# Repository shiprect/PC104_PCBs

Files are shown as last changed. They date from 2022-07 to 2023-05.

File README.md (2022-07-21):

# PC104_PCBs
This repository contains a collection of PC104 form factor PCB designs used on a variety of projects.

__Branches__

_previous-revision_  :  for the previous iteration of the pcb that was manufactured

_current-revision_   :  the pcb files that we are currently updating/working on

_production_         : for the version we have currently ordered/produced/are testing

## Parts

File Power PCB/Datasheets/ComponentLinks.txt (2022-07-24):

Solar Cells
https://www.digikey.com/en/products/detail/anysolar-ltd/KXOB25-14X1F-TR/9990479

Bat54 Schottky Diode
https://www.digikey.com/en/products/detail/onsemi/BAT54LT1G/917810

Power Good Switch
https://www.mouser.com/ProductDetail/Texas-Instruments/TPS22810DBVR?qs=34RfhUjJmKcFqeJVMZZhPA%3D%3D

Batteries
https://www.digikey.com/en/products/detail/zeus-battery-products/PCIFR18650-1500/9828824

Battery Charger
https://www.digikey.com/en/products/detail/analog-devices-inc/LTC4162IUFD-FAD-PBF/9446112

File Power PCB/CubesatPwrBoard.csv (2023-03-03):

Source: | /home/khronos/Desktop/Power PCB/CubesatPwrBoard.kicad_sch
Date: | Wed 09 Nov 2022 06:24:06 PM CST
Tool: | Eeschema 6.0.7
Generator: | /usr/share/kicad/plugins/bom_csv_grouped_by_value.py
Component Count: | 119
Individual Components:
Item | Qty | Reference(s) | Value | LibPart | Footprint | Datasheet | MANUFACTURER | MAXIMUM_PACKAGE_HEIGHT | PARTREV | STANDARD
 |  | BT1 | 254TR | 254TR:254TR | 254TR:BAT_254TR |  | Keystone Electronics | 17.215 mm | A | Manufacturer Recommendations
 |  | BT2 | 254TR | 254TR:254TR | 254TR:BAT_254TR |  | Keystone Electronics | 17.215 mm | A | Manufacturer Recommendations
 |  | BT3 | 254TR | 254TR:254TR | 254TR:BAT_254TR |  | Keystone Electronics | 17.215 mm | A | Manufacturer Recommendations
 |  | BT4 | 254TR | 254TR:254TR | 254TR:BAT_254TR |  | Keystone Electronics | 17.215 mm | A | Manufacturer Recommendations
 |  | BT5 | 254TR | 254TR:254TR | 254TR:BAT_254TR |  | Keystone Electronics | 17.215 mm | A | Manufacturer Recommendations
 |  | BT6 | 254TR | 254TR:254TR | 254TR:BAT_254TR |  | Keystone Electronics | 17.215 mm | A | Manufacturer Recommendations
 |  | BT7 | 254TR | 254TR:254TR | 254TR:BAT_254TR |  | Keystone Electronics | 17.215 mm | A | Manufacturer Recommendations
 |  | BT8 | 254TR | 254TR:254TR | 254TR:BAT_254TR |  | Keystone Electronics | 17.215 mm | A | Manufacturer Recommendations
 |  | C1 | C_Polarized_US | Device:C_Polarized_US | Capacitor_SMD:C_0603_1608Metric_Pad1.08x0.95mm_HandSolder | ~
 |  | C2 | C_Polarized_US | Device:C_Polarized_US | Capacitor_SMD:C_0603_1608Metric_Pad1.08x0.95mm_HandSolder | ~
 |  | C3 | C | Device:C | Capacitor_SMD:C_0603_1608Metric_Pad1.08x0.95mm_HandSolder | ~
 |  | C4 | C | Device:C | Capacitor_SMD:C_0603_1608Metric_Pad1.08x0.95mm_HandSolder | ~
 |  | C5 | C | Device:C | Capacitor_SMD:C_0603_1608Metric_Pad1.08x0.95mm_HandSolder | ~
 |  | C6 | C | Device:C | Capacitor_SMD:C_0603_1608Metric_Pad1.08x0.95mm_HandSolder | ~
 |  | C7 | C | Device:C | Capacitor_SMD:C_0603_1608Metric_Pad1.08x0.95mm_HandSolder | ~
 |  | C8 | 150u | Device:C_Polarized_US | Capacitor_SMD:C_0603_1608Metric_Pad1.08x0.95mm_HandSolder | ~
 |  | C9 | C_Polarized_US | Device:C_Polarized_US | Capacitor_SMD:C_0603_1608Metric_Pad1.08x0.95mm_HandSolder | ~
 |  | C10 | 1u | Device:C | Capacitor_SMD:C_0603_1608Metric_Pad1.08x0.95mm_HandSolder | ~
 |  | C11 | 4.7u | Device:C | Capacitor_SMD:C_0603_1608Metric_Pad1.08x0.95mm_HandSolder | ~
 |  | C12 | C | Device:C | Capacitor_SMD:C_0603_1608Metric_Pad1.08x0.95mm_HandSolder | ~
 |  | C13 | 10u | Device:C | Capacitor_SMD:C_0603_1608Metric_Pad1.08x0.95mm_HandSolder | ~
 |  | C14 | 10u | Device:C | Capacitor_SMD:C_0603_1608Metric_Pad1.08x0.95mm_HandSolder | ~
 |  | C15 | 150u | Device:C_Polarized_US | Capacitor_SMD:C_0603_1608Metric_Pad1.08x0.95mm_HandSolder | ~
 |  | C16 | C_Polarized_US | Device:C_Polarized_US | Capacitor_SMD:C_0603_1608Metric_Pad1.08x0.95mm_HandSolder | ~
 |  | C17 | 1u | Device:C | Capacitor_SMD:C_0603_1608Metric_Pad1.08x0.95mm_HandSolder | ~
 |  | C18 | 4.7u | Device:C | Capacitor_SMD:C_0603_1608Metric_Pad1.08x0.95mm_HandSolder | ~
 |  | C19 | C | Device:C | Capacitor_SMD:C_0603_1608Metric_Pad1.08x0.95mm_HandSolder | ~
 |  | C20 | 10u | Device:C | Capacitor_SMD:C_0603_1608Metric_Pad1.08x0.95mm_HandSolder | ~
 |  | C21 | 10u | Device:C | Capacitor_SMD:C_0603_1608Metric_Pad1.08x0.95mm_HandSolder | ~
 |  | C22 | 150u | Device:C_Polarized_US | Capacitor_SMD:C_0603_1608Metric_Pad1.08x0.95mm_HandSolder | ~
 |  | C23 | C_Polarized_US | Device:C_Polarized_US | Capacitor_SMD:C_0603_1608Metric_Pad1.08x0.95mm_HandSolder | ~
 |  | C24 | 1u | Device:C | Capacitor_SMD:C_0603_1608Metric_Pad1.08x0.95mm_HandSolder | ~
 |  | C25 | 4.7u | Device:C | Capacitor_SMD:C_0603_1608Metric_Pad1.08x0.95mm_HandSolder | ~
 |  | C26 | C | Device:C | Capacitor_SMD:C_0603_1608Metric_Pad1.08x0.95mm_HandSolder | ~
 |  | C27 | 10u | Device:C | Capacitor_SMD:C_0603_1608Metric_Pad1.08x0.95mm_HandSolder | ~
 |  | C28 | 10u | Device:C | Capacitor_SMD:C_0603_1608Metric_Pad1.08x0.95mm_HandSolder | ~
 |  | C29 | C_Polarized_US | Device:C_Polarized_US | Capacitor_SMD:C_0603_1608Metric_Pad1.08x0.95mm_HandSolder | ~
 |  | C30 | C_Polarized_US | Device:C_Polarized_US | Capacitor_SMD:C_0603_1608Metric_Pad1.08x0.95mm_HandSolder | ~
 |  | C31 | 4.7u | Device:C_Polarized_US | Capacitor_SMD:C_0603_1608Metric_Pad1.08x0.95mm_HandSolder | ~
 |  | C32 | 100u | Device:C_Polarized_US | Capacitor_SMD:C_0603_1608Metric_Pad1.08x0.95mm_HandSolder | ~
 |  | C33 | 4.7u | Device:C_Polarized_US | Capacitor_SMD:C_0603_1608Metric_Pad1.08x0.95mm_HandSolder | ~
 |  | C34 | 100u | Device:C_Polarized_US | Capacitor_SMD:C_0603_1608Metric_Pad1.08x0.95mm_HandSolder | ~
 |  | C35 | 4.7u | Device:C_Polarized_US | Capacitor_SMD:C_0603_1608Metric_Pad1.08x0.95mm_HandSolder | ~
 |  | C36 | 100u | Device:C_Polarized_US | Capacitor_SMD:C_0603_1608Metric_Pad1.08x0.95mm_HandSolder | ~
 |  | D1 | D_Schottky_Small | Device:D_Schottky_Small | CUS520,H3F:DIO_CUS520,H3F | ~
 |  | D2 | D_Schottky_Small | Device:D_Schottky_Small | CUS520,H3F:DIO_CUS520,H3F | ~
 |  | D3 | D_Schottky_Small | Device:D_Schottky_Small | CUS520,H3F:DIO_CUS520,H3F | ~
 |  | D4 | D_Schottky_Small | Device:D_Schottky_Small | CUS520,H3F:DIO_CUS520,H3F | ~
 |  | D5 | D_Schottky | Device:D_Schottky | Diode_SMD:D_0603_1608Metric_Pad1.05x0.95mm_HandSolder | ~
 |  | D6 | D_Schottky | Device:D_Schottky | Diode_SMD:D_0603_1608Metric_Pad1.05x0.95mm_HandSolder | ~
 |  | D7 | D_Schottky | Device:D_Schottky | Diode_SMD:D_0603_1608Metric_Pad1.05x0.95mm_HandSolder | ~
 |  | D8 | D_Schottky | Device:D_Schottky | Diode_SMD:D_0603_1608Metric_Pad1.05x0.95mm_HandSolder | ~
 |  | H1 | MountingHole_Pad | Mechanical:MountingHole_Pad | MountingHole:MountingHole_4.3mm_M4_DIN965_Pad | ~
 |  | H2 | MountingHole_Pad | Mechanical:MountingHole_Pad | MountingHole:MountingHole_4.3mm_M4_DIN965_Pad | ~
 |  | H3 | MountingHole_Pad | Mechanical:MountingHole_Pad | MountingHole:MountingHole_4.3mm_M4_DIN965_Pad | ~
 |  | H4 | MountingHole_Pad | Mechanical:MountingHole_Pad | MountingHole:MountingHole_4.3mm_M4_DIN965_Pad | ~
 |  | J1 | Conn_01x04_Female | Connector:Conn_01x04_Female | Connector_PinHeader_2.54mm:PinHeader_1x04_P2.54mm_Vertical | ~
 |  | J2 | Conn_01x04_Female | Connector:Conn_01x04_Female | Connector_PinHeader_2.54mm:PinHeader_1x04_P2.54mm_Vertical | ~
 |  | J3 | Conn_01x04_Female | Connector:Conn_01x04_Female | Connector_PinHeader_2.54mm:PinHeader_1x04_P2.54mm_Vertical | ~
 |  | J4 | Conn_01x04_Female | Connector:Conn_01x04_Female | Connector_PinHeader_2.54mm:PinHeader_1x04_P2.54mm_Vertical | ~
 |  | J5 | Conn_01x04_Female | Connector:Conn_01x04_Female | Connector_PinHeader_2.54mm:PinHeader_1x04_P2.54mm_Vertical | ~
 |  | J6 | Conn_01x03_Female | Connector:Conn_01x03_Female | Connector_PinSocket_2.54mm:PinSocket_1x03_P2.54mm_Vertical | ~
 |  | J7 | Conn_01x03_Female | Connector:Conn_01x03_Female | Connector_PinSocket_2.54mm:PinSocket_1x03_P2.54mm_Vertical | ~
 |  | J8 | Conn_01x03_Female | Connector:Conn_01x03_Female | Connector_PinSocket_2.54mm:PinSocket_1x03_P2.54mm_Vertical | ~
 |  | J9 | Conn_01x03_Female | Connector:Conn_01x03_Female | Connector_PinSocket_2.54mm:PinSocket_1x03_P2.54mm_Vertical | ~
 |  | J10 | S1 | Connector:Conn_01x08_Female | Connector_PinSocket_2.54mm:PinSocket_2x04_P2.54mm_Vertical | ~
 |  | J11 | S2 | Connector:Conn_01x08_Female | Connector_PinSocket_2.54mm:PinSocket_2x04_P2.54mm_Vertical | ~
 |  | J12 | S3 | Connector:Conn_01x08_Female | Connector_PinSocket_2.54mm:PinSocket_2x04_P2.54mm_Vertical | ~
 |  | J13 | S4 | Connector:Conn_01x08_Female | Connector_PinSocket_2.54mm:PinSocket_2x04_P2.54mm_Vertical | ~
 |  | J14 | S5 | Connector:Conn_01x08_Female | Connector_PinSocket_2.54mm:PinSocket_2x04_P2.54mm_Vertical | ~
 |  | J15 | S6 | Connector:Conn_01x08_Female | Connector_PinSocket_2.54mm:PinSocket_2x04_P2.54mm_Vertical | ~
 |  | L1 | L | Device:L | Inductor_SMD:L_0603_1608Metric_Pad1.05x0.95mm_HandSolder | ~
 |  | L2 | 4.7u | Device:L | Inductor_SMD:L_0603_1608Metric_Pad1.05x0.95mm_HandSolder | ~
 |  | L3 | 4.7u | Device:L | Inductor_SMD:L_0603_1608Metric_Pad1.05x0.95mm_HandSolder | ~
 |  | L4 | 4.7u | Device:L | Inductor_SMD:L_0603_1608Metric_Pad1.05x0.95mm_HandSolder | ~
 |  | L5 | L | Device:L | Inductor_SMD:L_0603_1608Metric_Pad1.05x0.95mm_HandSolder | ~
 |  | L6 | 22u | Device:L | Inductor_SMD:L_0603_1608Metric_Pad1.05x0.95mm_HandSolder | ~
 |  | L7 | 22u | Device:L | Inductor_SMD:L_0603_1608Metric_Pad1.05x0.95mm_HandSolder | ~
 |  | L8 | 22u | Device:L | Inductor_SMD:L_0603_1608Metric_Pad1.05x0.95mm_HandSolder | ~
 |  | Q1 | TQM110NB04CR_RLG | TQM110NB04CR_RLG:TQM110NB04CR_RLG | TQM110N:TRANS_TQM110NB04CR_RLG |  | Taiwan Semiconductor | 1.1 mm | A1910 | Manufacturer Recommendations
 |  | Q2 | 2N7002* | 2N7002_:2N7002* | 2N7002:SOT23
 |  | Q3 | TQM110NB04CR_RLG | TQM110NB04CR_RLG:TQM110NB04CR_RLG | TQM110N:TRANS_TQM110NB04CR_RLG |  | Taiwan Semiconductor | 1.1 mm | A1910 | Manufacturer Recommendations
 |  | Q4 | 2N7002* | 2N7002_:2N7002* | 2N7002:SOT23
 |  | Q5 | TQM110NB04CR_RLG | TQM110NB04CR_RLG:TQM110NB04CR_RLG | TQM110N:TRANS_TQM110NB04CR_RLG |  | Taiwan Semiconductor | 1.1 mm | A1910 | Manufacturer Recommendations
 |  | Q6 | 2N7002* | 2N7002_:2N7002* | 2N7002:SOT23
 |  | Q7 | TQM110NB04CR_RLG | TQM110NB04CR_RLG:TQM110NB04CR_RLG | TQM110N:TRANS_TQM110NB04CR_RLG |  | Taiwan Semiconductor | 1.1 mm | A1910 | Manufacturer Recommendations
 |  | Q8 | 2N7002* | 2N7002_:2N7002* | 2N7002:SOT23
 |  | R1 | R | Device:R | Resistor_SMD:R_0603_1608Metric_Pad0.98x0.95mm_HandSolder | ~
 |  | R2 | R | Device:R | Resistor_SMD:R_0603_1608Metric_Pad0.98x0.95mm_HandSolder | ~
 |  | R3 | R | Device:R | Resistor_SMD:R_0603_1608Metric_Pad0.98x0.95mm_HandSolder | ~
 |  | R4 | R | Device:R | Resistor_SMD:R_0603_1608Metric_Pad0.98x0.95mm_HandSolder | ~
 |  | R5 | R | Device:R | Resistor_SMD:R_0603_1608Metric_Pad0.98x0.95mm_HandSolder | ~
 |  | R6 | 2.5 | Device:R | Resistor_SMD:R_0603_1608Metric_Pad0.98x0.95mm_HandSolder | ~
 |  | R7 | 16m | Device:R | Resistor_SMD:R_0603_1608Metric_Pad0.98x0.95mm_HandSolder | ~
 |  | R8 | 16m | Device:R | Resistor_SMD:R_0603_1608Metric_Pad0.98x0.95mm_HandSolder | ~
 |  | R9 | 63.4k | Device:R | Resistor_SMD:R_0603_1608Metric_Pad0.98x0.95mm_HandSolder | ~
 |  | R10 | 10m | Device:R | Resistor_SMD:R_0603_1608Metric_Pad0.98x0.95mm_HandSolder | ~
 |  | R11 | 2.5 | Device:R | Resistor_SMD:R_0603_1608Metric_Pad0.98x0.95mm_HandSolder | ~
 |  | R12 | 16m | Device:R | Resistor_SMD:R_0603_1608Metric_Pad0.98x0.95mm_HandSolder | ~
 |  | R13 | 16m | Device:R | Resistor_SMD:R_0603_1608Metric_Pad0.98x0.95mm_HandSolder | ~
 |  | R14 | 63.4k | Device:R | Resistor_SMD:R_0603_1608Metric_Pad0.98x0.95mm_HandSolder | ~
 |  | R15 | 10m | Device:R | Resistor_SMD:R_0603_1608Metric_Pad0.98x0.95mm_HandSolder | ~
 |  | R16 | 2.5 | Device:R | Resistor_SMD:R_0603_1608Metric_Pad0.98x0.95mm_HandSolder | ~
 |  | R17 | 16m | Device:R | Resistor_SMD:R_0603_1608Metric_Pad0.98x0.95mm_HandSolder | ~
 |  | R18 | 16m | Device:R | Resistor_SMD:R_0603_1608Metric_Pad0.98x0.95mm_HandSolder | ~
 |  | R19 | 63.4k | Device:R | Resistor_SMD:R_0603_1608Metric_Pad0.98x0.95mm_HandSolder | ~
 |  | R20 | 10m | Device:R | Resistor_SMD:R_0603_1608Metric_Pad0.98x0.95mm_HandSolder | ~
 |  | TH1 | Thermistor_NTC | Device:Thermistor_NTC | Resistor_SMD:R_0402_1005Metric_Pad0.72x0.64mm_HandSolder | ~
 |  | TH2 | Thermistor_NTC | Device:Thermistor_NTC | Resistor_SMD:R_0402_1005Metric_Pad0.72x0.64mm_HandSolder | ~
 |  | TH3 | Thermistor_NTC | Device:Thermistor_NTC | Resistor_SMD:R_0402_1005Metric_Pad0.72x0.64mm_HandSolder | ~
 |  | TH4 | Thermistor_NTC | Device:Thermistor_NTC | Resistor_SMD:R_0402_1005Metric_Pad0.72x0.64mm_HandSolder | ~
 |  | U1 | LTC4162 | LTC4162IUFD:LTC4162 | LTC4162:QFN50P500X400X80-29N
 |  | U2 | LTC4162 | LTC4162IUFD:LTC4162 | LTC4162:QFN50P500X400X80-29N
 |  | U3 | LTC4162 | LTC4162IUFD:LTC4162 | LTC4162:QFN50P500X400X80-29N
 |  | U4 | LTC4162 | LTC4162IUFD:LTC4162 | LTC4162:QFN50P500X400X80-29N
 |  | U5 | MAX710ESE+T | MAX710ESE_T:MAX710ESE+T | MAX710ESE:SOIC127P600X175-16N
 |  | U6 | MAX710ESE+T | MAX710ESE_T:MAX710ESE+T | MAX710ESE:SOIC127P600X175-16N
 |  | U7 | MAX710ESE+T | MAX710ESE_T:MAX710ESE+T | MAX710ESE:SOIC127P600X175-16N
 |  | U8 | MAX710ESE+T | MAX710ESE_T:MAX710ESE+T | MAX710ESE:SOIC127P600X175-16N
Collated Components:
Item | Qty | Reference(s) | Value | LibPart | Footprint | Datasheet | MANUFACTURER | MAXIMUM_PACKAGE_HEIGHT | PARTREV | STANDARD
1 | 8 | BT1, BT2, BT3, BT4, BT5, BT6, BT7, BT8 | 254TR | 254TR:254TR | 254TR:BAT_254TR |  | Keystone Electronics | 17.215 mm | A | Manufacturer Recommendations
2 | 7 | C1, C2, C9, C16, C23, C29, C30 | C_Polarized_US | Device:C_Polarized_US | Capacitor_SMD:C_0603_1608Metric_Pad1.08x0.95mm_HandSolder | ~
3 | 8 | C3, C4, C5, C6, C7, C12, C19, C26 | C | Device:C | Capacitor_SMD:C_0603_1608Metric_Pad1.08x0.95mm_HandSolder | ~
4 | 3 | C8, C15, C22 | 150u | Device:C_Polarized_US | Capacitor_SMD:C_0603_1608Metric_Pad1.08x0.95mm_HandSolder | ~
5 | 3 | C10, C17, C24 | 1u | Device:C | Capacitor_SMD:C_0603_1608Metric_Pad1.08x0.95mm_HandSolder | ~
6 | 3 | C11, C18, C25 | 4.7u | Device:C | Capacitor_SMD:C_0603_1608Metric_Pad1.08x0.95mm_HandSolder | ~
7 | 6 | C13, C14, C20, C21, C27, C28 | 10u | Device:C | Capacitor_SMD:C_0603_1608Metric_Pad1.08x0.95mm_HandSolder | ~
8 | 3 | C31, C33, C35 | 4.7u | Device:C_Polarized_US | Capacitor_SMD:C_0603_1608Metric_Pad1.08x0.95mm_HandSolder | ~
9 | 3 | C32, C34, C36 | 100u | Device:C_Polarized_US | Capacitor_SMD:C_0603_1608Metric_Pad1.08x0.95mm_HandSolder | ~
10 | 4 | D1, D2, D3, D4 | D_Schottky_Small | Device:D_Schottky_Small | CUS520,H3F:DIO_CUS520,H3F | ~
11 | 4 | D5, D6, D7, D8 | D_Schottky | Device:D_Schottky | Diode_SMD:D_0603_1608Metric_Pad1.05x0.95mm_HandSolder | ~
12 | 4 | H1, H2, H3, H4 | MountingHole_Pad | Mechanical:MountingHole_Pad | MountingHole:MountingHole_4.3mm_M4_DIN965_Pad | ~
13 | 5 | J1, J2, J3, J4, J5 | Conn_01x04_Female | Connector:Conn_01x04_Female | Connector_PinHeader_2.54mm:PinHeader_1x04_P2.54mm_Vertical | ~
14 | 4 | J6, J7, J8, J9 | Conn_01x03_Female | Connector:Conn_01x03_Female | Connector_PinSocket_2.54mm:PinSocket_1x03_P2.54mm_Vertical | ~
15 | 1 | J10 | S1 | Connector:Conn_01x08_Female | Connector_PinSocket_2.54mm:PinSocket_2x04_P2.54mm_Vertical | ~
16 | 1 | J11 | S2 | Connector:Conn_01x08_Female | Connector_PinSocket_2.54mm:PinSocket_2x04_P2.54mm_Vertical | ~
17 | 1 | J12 | S3 | Connector:Conn_01x08_Female | Connector_PinSocket_2.54mm:PinSocket_2x04_P2.54mm_Vertical | ~
18 | 1 | J13 | S4 | Connector:Conn_01x08_Female | Connector_PinSocket_2.54mm:PinSocket_2x04_P2.54mm_Vertical | ~
19 | 1 | J14 | S5 | Connector:Conn_01x08_Female | Connector_PinSocket_2.54mm:PinSocket_2x04_P2.54mm_Vertical | ~
20 | 1 | J15 | S6 | Connector:Conn_01x08_Female | Connector_PinSocket_2.54mm:PinSocket_2x04_P2.54mm_Vertical | ~
21 | 2 | L1, L5 | L | Device:L | Inductor_SMD:L_0603_1608Metric_Pad1.05x0.95mm_HandSolder | ~
22 | 3 | L2, L3, L4 | 4.7u | Device:L | Inductor_SMD:L_0603_1608Metric_Pad1.05x0.95mm_HandSolder | ~
23 | 3 | L6, L7, L8 | 22u | Device:L | Inductor_SMD:L_0603_1608Metric_Pad1.05x0.95mm_HandSolder | ~
24 | 4 | Q1, Q3, Q5, Q7 | TQM110NB04CR_RLG | TQM110NB04CR_RLG:TQM110NB04CR_RLG | TQM110N:TRANS_TQM110NB04CR_RLG |  | Taiwan Semiconductor | 1.1 mm | A1910 | Manufacturer Recommendations
25 | 4 | Q2, Q4, Q6, Q8 | 2N7002* | 2N7002_:2N7002* | 2N7002:SOT23
26 | 5 | R1, R2, R3, R4, R5 | R | Device:R | Resistor_SMD:R_0603_1608Metric_Pad0.98x0.95mm_HandSolder | ~
27 | 3 | R6, R11, R16 | 2.5 | Device:R | Resistor_SMD:R_0603_1608Metric_Pad0.98x0.95mm_HandSolder | ~
28 | 6 | R7, R8, R12, R13, R17, R18 | 16m | Device:R | Resistor_SMD:R_0603_1608Metric_Pad0.98x0.95mm_HandSolder | ~
29 | 3 | R9, R14, R19 | 63.4k | Device:R | Resistor_SMD:R_0603_1608Metric_Pad0.98x0.95mm_HandSolder | ~
30 | 3 | R10, R15, R20 | 10m | Device:R | Resistor_SMD:R_0603_1608Metric_Pad0.98x0.95mm_HandSolder | ~
31 | 4 | TH1, TH2, TH3, TH4 | Thermistor_NTC | Device:Thermistor_NTC | Resistor_SMD:R_0402_1005Metric_Pad0.72x0.64mm_HandSolder | ~
32 | 4 | U1, U2, U3, U4 | LTC4162 | LTC4162IUFD:LTC4162 | LTC4162:QFN50P500X400X80-29N
33 | 4 | U5, U6, U7, U8 | MAX710ESE+T | MAX710ESE_T:MAX710ESE+T | MAX710ESE:SOIC127P600X175-16N

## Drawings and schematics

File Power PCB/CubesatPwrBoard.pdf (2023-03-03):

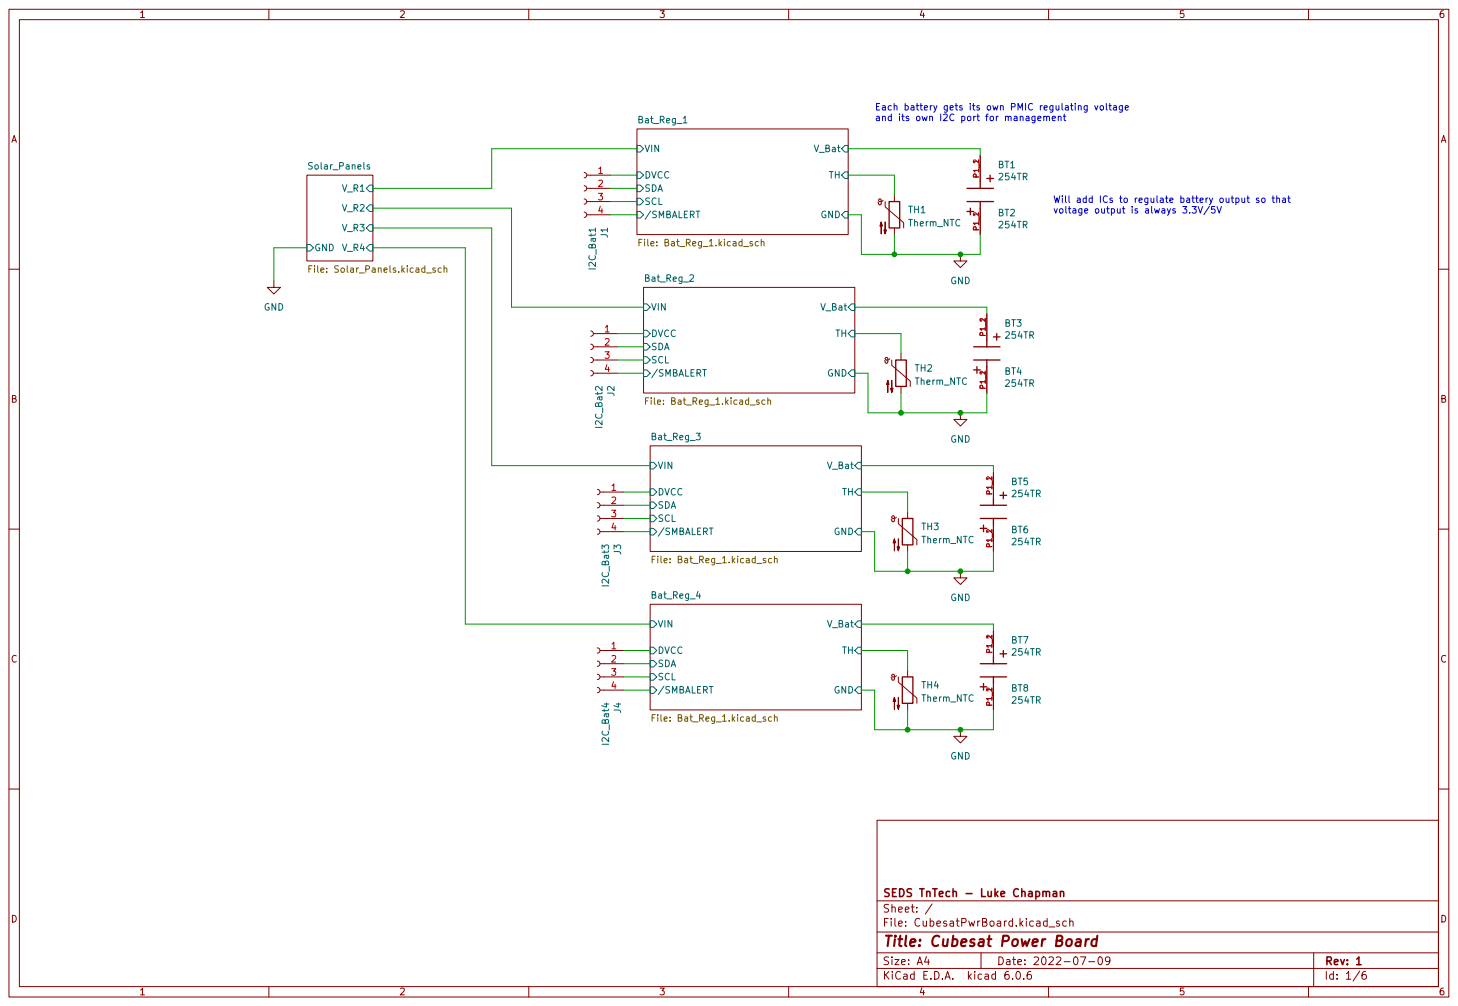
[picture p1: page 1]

Each battery gets its own PMIC regulating voltage
and its own I2C port for management

Will add ICs to regulate battery output so that
voltage output is always 3.3V/5V

File: CubesatPwrBoard.kicad_sch Sheet: / SEDS TnTech - Luke Chapman

Id: 1/6 Title: Cubesat Power Board

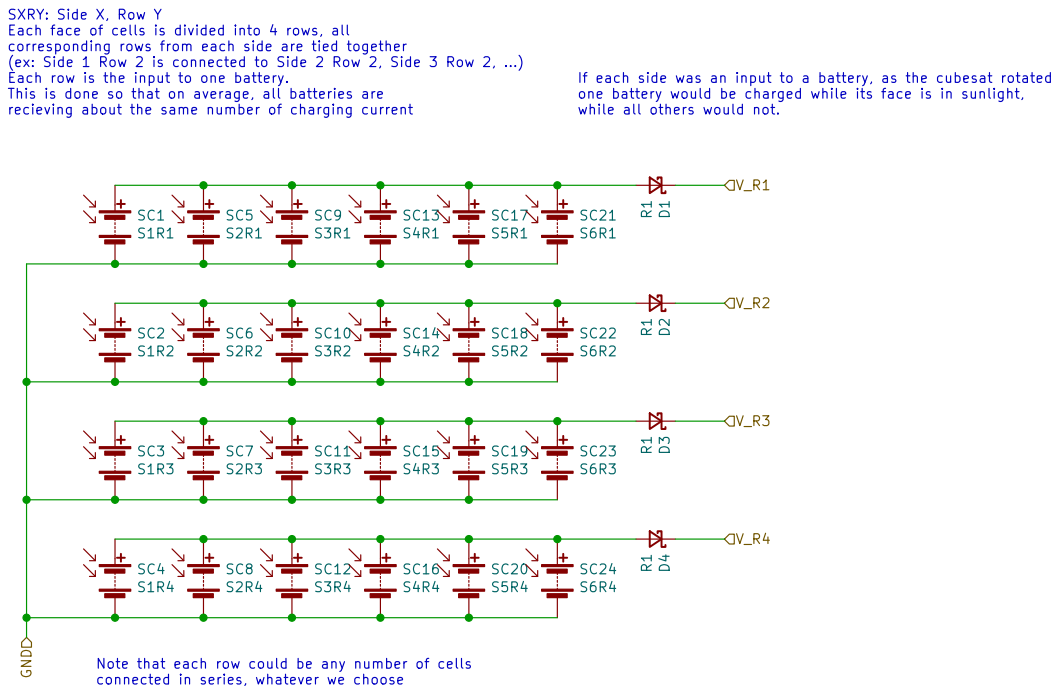
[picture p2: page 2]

V_R3 V_R4 V_R1 V_R2 SXRY: Side X, Row Y
Each face of cells is divided into 4 rows, all corresponding rows from each side are tied together

(ex: Side 1 Row 2 is connected to Side 2 Row 2, Side 3 Row 2, ...)
Each row is the input to one battery.
This is done so that on average, all batteries are
recieving about the same number of charging current

If each side was an input to a battery, as the cubesat rotated

one battery would be charged while its face is in sunlight, while all others would not. Note that each row could be any number of cells

connected in series, whatever we choose

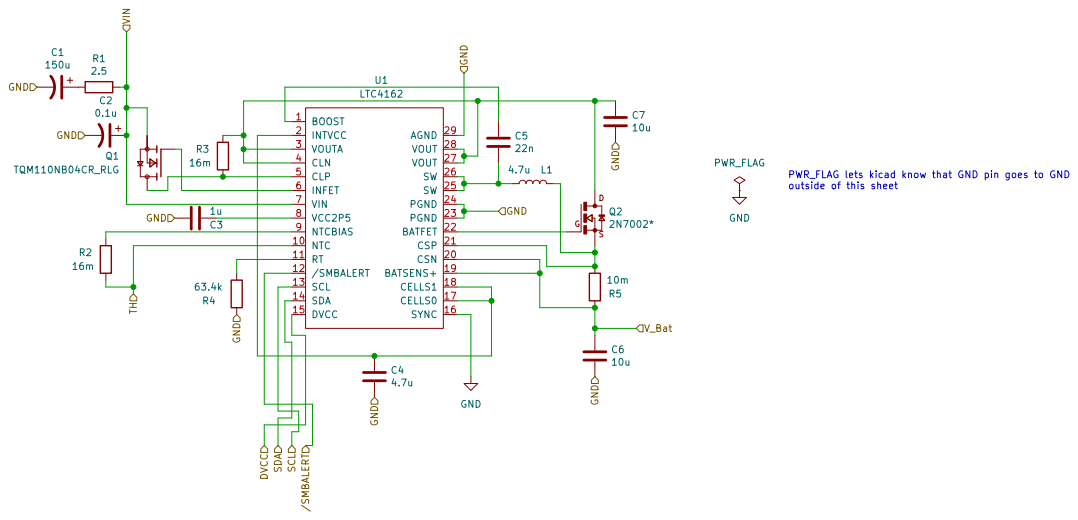
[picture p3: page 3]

PWR_FLAG lets kicad know that GND pin goes to GND
outside of this sheet

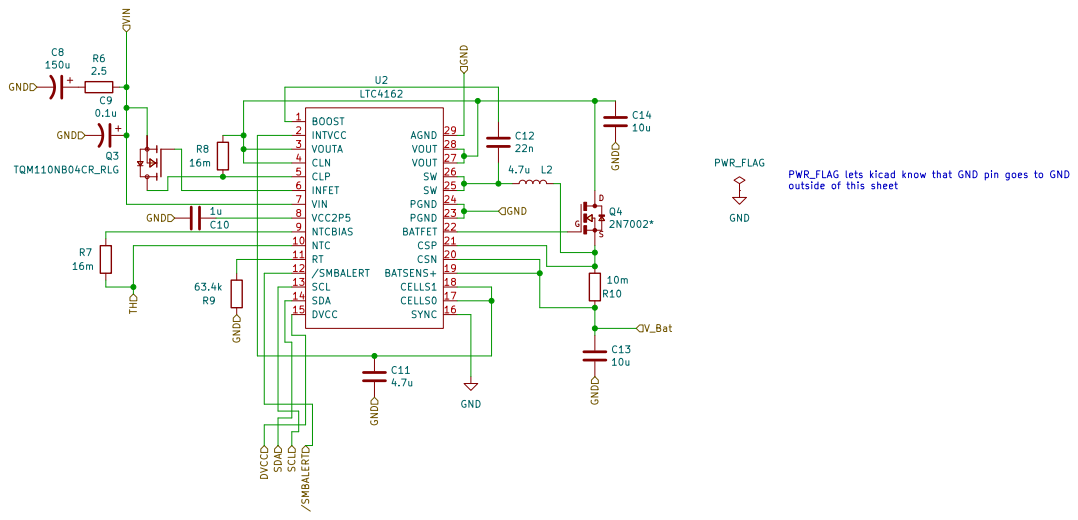
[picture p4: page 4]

PWR_FLAG lets kicad know that GND pin goes to GND
outside of this sheet

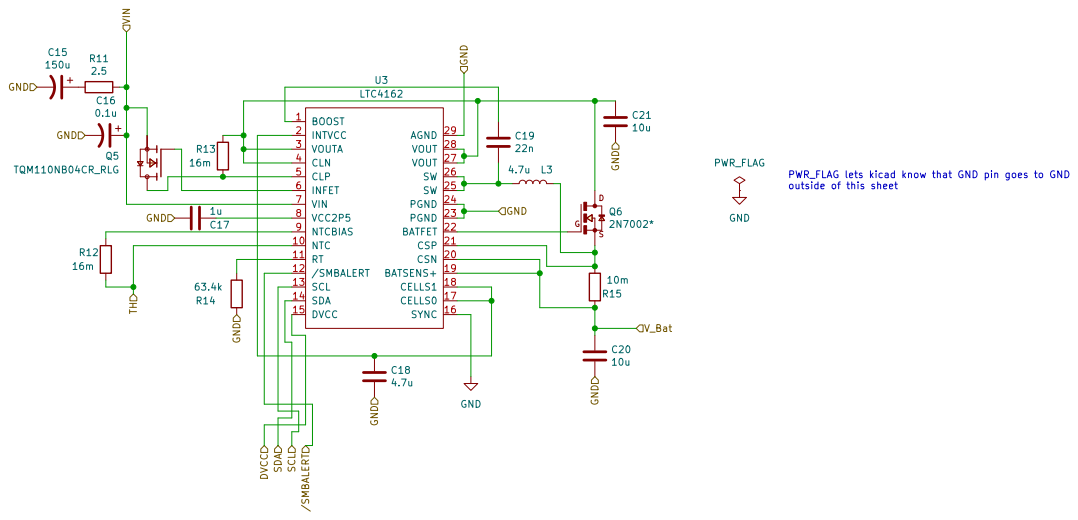
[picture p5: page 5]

PWR_FLAG lets kicad know that GND pin goes to GND
outside of this sheet

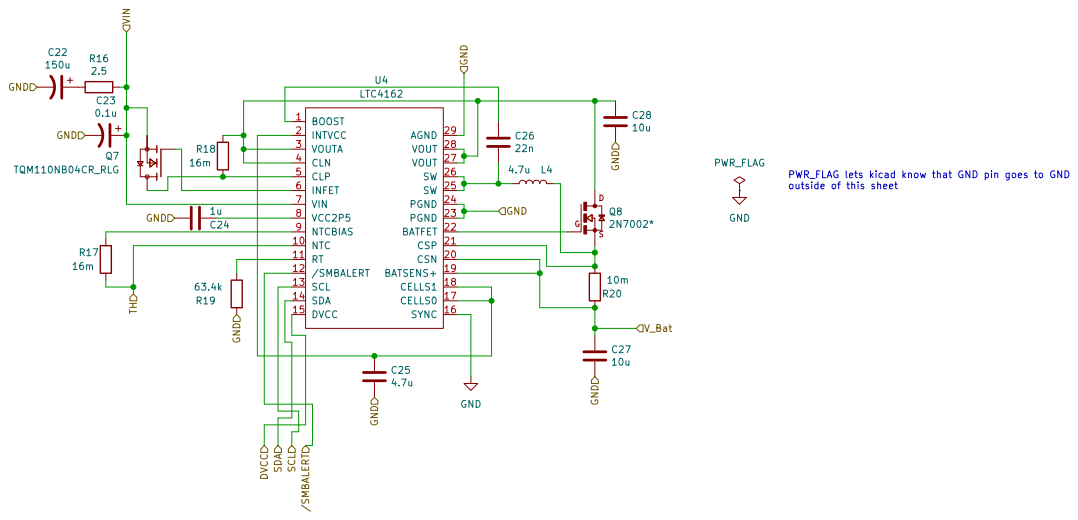
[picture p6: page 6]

PWR_FLAG lets kicad know that GND pin goes to GND
outside of this sheet

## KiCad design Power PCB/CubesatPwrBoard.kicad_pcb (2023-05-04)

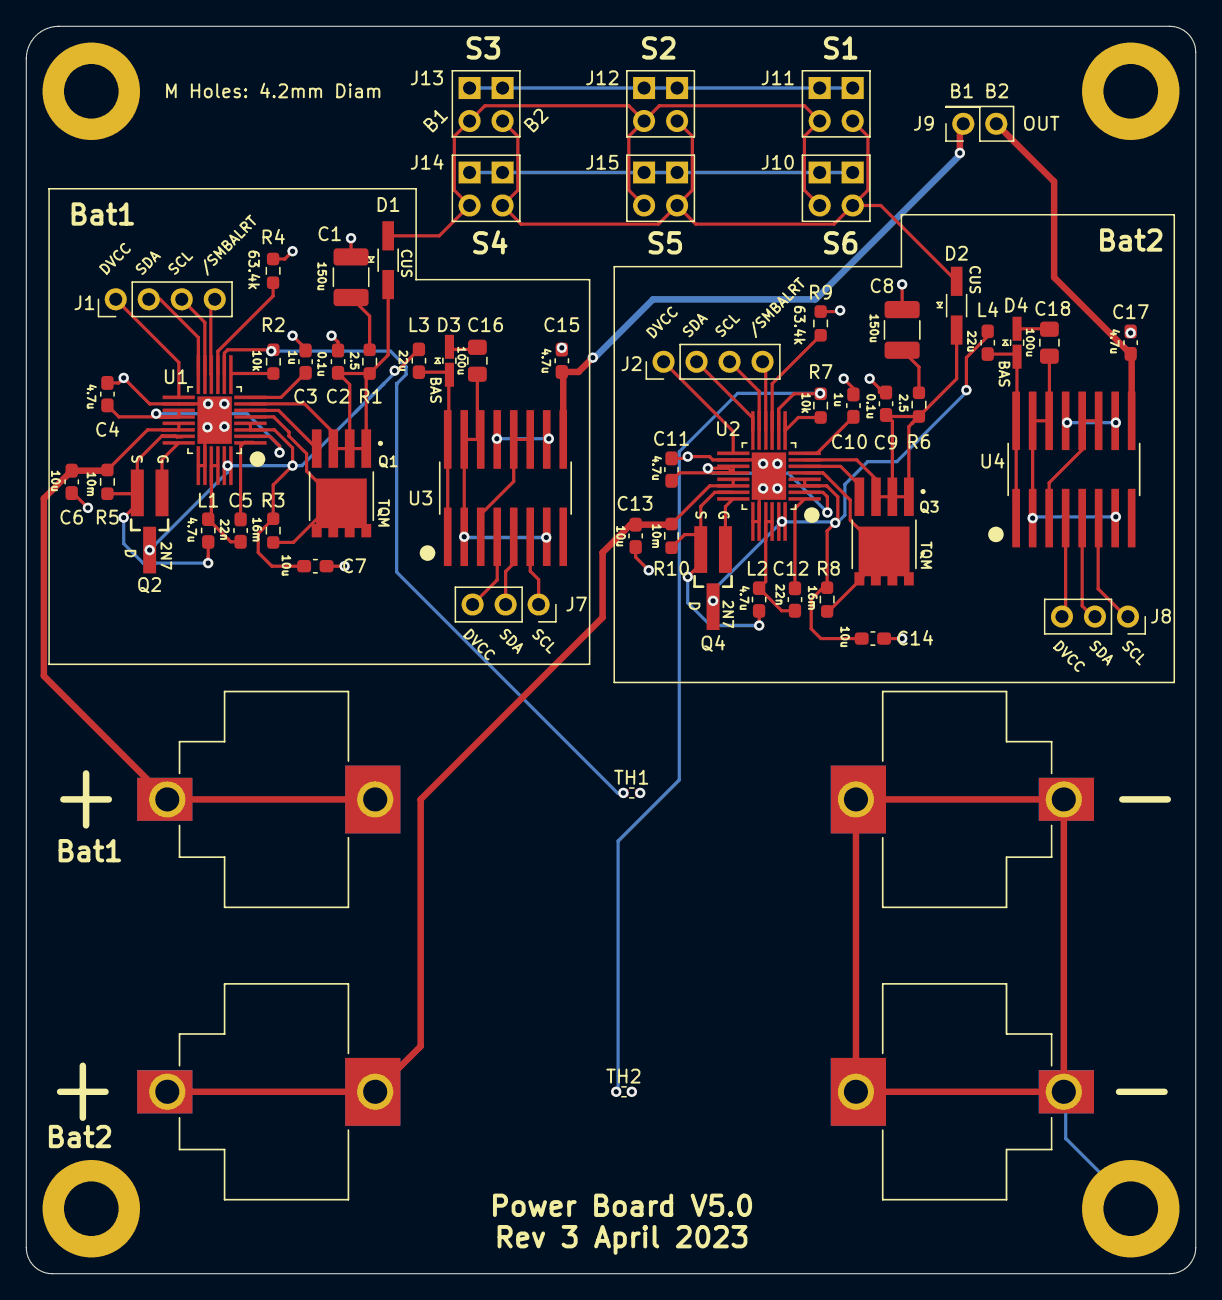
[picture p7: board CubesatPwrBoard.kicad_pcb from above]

Board: 2 copper layers, 90.0 x 96.0 mm, 65 parts (0 on the bottom side), 57 nets.

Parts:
C1, C8: 150u; C_1210_3225Metric_Pad1.33x2.70mm_HandSolder
C2, C9: 0.1u; C_0603_1608Metric_Pad1.08x0.95mm_HandSolder
C3, C10: 1u; C_0603_1608Metric_Pad1.08x0.95mm_HandSolder
C4, C11, C15, C17: 4.7u; C_0603_1608Metric_Pad1.08x0.95mm_HandSolder
C5, C12: 22n; C_0603_1608Metric_Pad1.08x0.95mm_HandSolder
C6, C7, C13, C14: 10u; C_0603_1608Metric_Pad1.08x0.95mm_HandSolder
C16, C18: 100u; C_0805_2012Metric_Pad1.18x1.45mm_HandSolder
D1, D2: D_Schottky_Small; CubeSat_DIO_CUS520,H3f
D3, D4: D_Schottky; CubeSat_Diode_SOT_882
H1, H2, H3, H4: MountingHole_Pad; CubeSat_MountingHole_M4
J1, J2: Conn_01x04_Female; CubeSat_Conn_4x01_P2.54mm
J3, J4, J5, J6: 254TR; BAT_254TR
J7, J8: Conn_01x03_Female; CubeSat_Conn_3x01_P2.54mm
J9: Conn_01x02_Female; CubeSat_Conn_2x01_P2.54mm
J10: S1; CubeSat_Conn_2x02_P2.54mm
J11: S2; CubeSat_Conn_2x02_P2.54mm
J12: S3; CubeSat_Conn_2x02_P2.54mm
J13: S4; CubeSat_Conn_2x02_P2.54mm
J14: S5; CubeSat_Conn_2x02_P2.54mm
J15: S6; CubeSat_Conn_2x02_P2.54mm
L1, L2: 4.7u; L_0603_1608Metric_Pad1.05x0.95mm_HandSolder
L3, L4: 22u; L_0603_1608Metric_Pad1.05x0.95mm_HandSolder
Q1, Q3: TQM110NB04CR_RLG; TRANS_TQM110NB04CR_RLG
Q2, Q4: 2N7002*; CubeSat_2n7002
R1, R6: 2.5; R_0603_1608Metric_Pad0.98x0.95mm_HandSolder
R2, R7: 10k; R_0603_1608Metric_Pad0.98x0.95mm_HandSolder
R3, R8: 16m; R_0603_1608Metric_Pad0.98x0.95mm_HandSolder
R4, R9: 63.4k; R_0603_1608Metric_Pad0.98x0.95mm_HandSolder
R5, R10: 10m; R_0603_1608Metric_Pad0.98x0.95mm_HandSolder
TH1, TH2: Thermistor_NTC; R_0402_1005Metric_Pad0.72x0.64mm_HandSolder
U1, U2: LTC4162; QFN50P500X400X80-29N
U3, U4: MAX710ESE+T; SOIC127P600X175-16N

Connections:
/Bat_Reg_3/DVCC: J2.1, U2.15 (DVCC)
/Bat_Reg_3/SCL: J2.3, U2.13 (SCL)
/Bat_Reg_3/SDA: J2.2, U2.14 (SDA)
/Bat_Reg_3/TH: R7.2, TH2.1, U2.10 (NTC)
/Bat_Reg_3/VIN: C9.1, D2.1 (K), Q3.1, Q3.2, Q3.3, R6.1, U2.7 (VIN)
/Bat_Reg_3/V_Bat: C13.1, J5.P1_1, J5.P1_2, R10.1, U2.19 (BATSENS+), U2.20 (CSN)
/Bat_Reg_3/V_Out: C14.1, L4.1, Q4.3, R8.1, U2.3 (VOUTA), U2.4 (CLN), U2.27 (VOUT), U2.28 (VOUT)
/Bat_Reg_3//SMBALERT: J2.4, U2.12 (/SMBALERT)
/Bat_Reg_4/DVCC: J1.1, U1.15 (DVCC)
/Bat_Reg_4/SCL: J1.3, U1.13 (SCL)
/Bat_Reg_4/SDA: J1.2, U1.14 (SDA)
/Bat_Reg_4/TH: R2.2, TH1.1, U1.10 (NTC)
/Bat_Reg_4/VIN: C2.1, D1.1 (K), Q1.1, Q1.2, Q1.3, R1.1, U1.7 (VIN)
/Bat_Reg_4/V_Bat: C6.1, J3.P1_1, J3.P1_2, R5.1, U1.19 (BATSENS+), U1.20 (CSN)
/Bat_Reg_4/V_Out: C7.1, L3.1, Q2.3, R3.1, U1.3 (VOUTA), U1.4 (CLN), U1.27 (VOUT), U1.28 (VOUT)
/Bat_Reg_4//SMBALERT: J1.4, U1.12 (/SMBALERT)
/V_Reg_3.3_5V3/3/#5: J8.1, U4.6 (3/~5)
/V_Reg_3.3_5V3/#SHDN: J8.3, U4.4 (~SHDN)
/V_Reg_3.3_5V3/#STBY: J8.2, U4.5 (~STBY)
/V_Reg_3.3_5V3/Vout: C17.1, J9.2, U4.9 (OUT)
/V_Reg_3.3_5V4/3/#5: J7.1, U3.6 (3/~5)
/V_Reg_3.3_5V4/#SHDN: J7.3, U3.4 (~SHDN)
/V_Reg_3.3_5V4/#STBY: J7.2, U3.5 (~STBY)
/V_Reg_3.3_5V4/Vout: C15.1, J9.1, U3.9 (OUT)
GND: C1.2, C2.2, C3.1, C4.2, C6.2, C7.2, C8.2, C9.2, C10.1, C11.2, C13.2, C14.2, C15.2, C16.2, C17.2, C18.2, H1.1, H2.1, H3.1, H4.1, J4.P1_1, J4.P1_2, J6.P1_1, J6.P1_2, J10.2, J10.4, J11.2, J11.4, J12.2, J12.4, J13.2, J13.4, J14.2, J14.4, J15.2, J15.4, R4.1, R9.1, TH1.2, TH2.2, U1.16 (SYNC), U1.23 (PGND), U1.24 (PGND), U1.29 (AGND), U2.16 (SYNC), U2.23 (PGND), U2.24 (PGND), U2.29 (AGND), U3.2 (PGND), U3.7 (N/~E), U3.14 (GND), U3.15 (PGND), U4.2 (PGND), U4.7 (N/~E), U4.14 (GND), U4.15 (PGND)
unnamed: C1.1, R1.2
unnamed: C3.2, U1.8 (VCC2P5)
unnamed: C4.1, U1.2 (INTVCC), U1.17 (CELLS0), U1.18 (CELLS1)
unnamed: C5.1, U1.1 (BOOST)
unnamed: C5.2, L1.1, U1.25 (SW), U1.26 (SW)
unnamed: C8.1, R6.2
unnamed: C10.2, U2.8 (VCC2P5)
unnamed: C11.1, U2.2 (INTVCC), U2.17 (CELLS0), U2.18 (CELLS1)
unnamed: C12.1, U2.1 (BOOST)
unnamed: C12.2, L2.1, U2.25 (SW), U2.26 (SW)
unnamed: C16.1, D3.1 (K)
unnamed: C18.1, D4.1 (K)
unnamed: D1.2 (A), J10.3, J11.3, J12.3, J13.3, J14.3, J15.3
unnamed: D2.2 (A), J10.1, J11.1, J12.1, J13.1, J14.1, J15.1
unnamed: D3.2 (A), L3.2, U3.1 (LX), U3.16 (LX)
unnamed: D4.2 (A), L4.2, U4.1 (LX), U4.16 (LX)
unnamed: L1.2, Q2.2, R5.2, U1.21 (CSP)
unnamed: L2.2, Q4.2, R10.2, U2.21 (CSP)
unnamed: Q1.4, U1.6 (INFET)
unnamed: Q1.5_8, R3.2, U1.5 (CLP)
unnamed: Q2.1, U1.22 (BATFET)
unnamed: Q3.4, U2.6 (INFET)
unnamed: Q3.5_8, R8.2, U2.5 (CLP)
unnamed: Q4.1, U2.22 (BATFET)
unnamed: R2.1, U1.9 (NTCBIAS)
unnamed: R4.2, U1.11 (RT)
unnamed: R7.1, U2.9 (NTCBIAS)
unnamed: R9.2, U2.11 (RT)
unnamed: U3.10 (LBI-), U3.13 (REF)
unnamed: U3.3 (ILIM), U3.11 (LBI+), U3.12 (PS)
unnamed: U4.10 (LBI-), U4.13 (REF)
unnamed: U4.3 (ILIM), U4.11 (LBI+), U4.12 (PS)

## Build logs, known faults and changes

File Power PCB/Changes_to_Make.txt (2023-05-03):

r10, r15, r5, r3, r8, r13 are wrong size - too big
might need to do thermistors by hand
check text orientation
r10, r5, r15, may need to be flipped to keep side connected to transistor on same side
text size
maybe flip c2, c4, c6. c9, c11, c13. c16, c18, c20
r6, c9, (and other) label placements
move q5 label down
make pin 1 location more obvious
increase font size for /SMBA, SCL, etc
for connectors, make all squares GND or something
remove the +'s from the battery connector footprints and have a + and - indicating pos and neg
remove BT1, BT2, ... from the silk screen
remove H1, H2, ... from silk screen
battery connectors need to be spaced out more and maybe removed
check if d6 etc. is the wrong kind and put on 606
visually separate Bat1, Bat2, circuitry

100u caps are 0805
secondary voltage reg IC diodes are SOD-882

make IC pads and transistor pads longer

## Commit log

2022-07-24 Current version commit
    committing current versions of power and esp32 to production branch
    [CubesatPwrBoard.csv, CubesatPwrBoard.kicad_pcb, CubesatPwrBoard.sch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]
2022-07-24 name change commit
    changed name from current to production
    [CubesatPwrBoard.csv, CubesatPwrBoard.kicad_pcb, CubesatPwrBoard.sch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]
2023-03-03 copies current-revision to production branch
    [Bat_Reg_1.kicad_sch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]
2023-03-03 Added missing component values
    [Bat_Reg_1.kicad_sch, CubesatPwrBoard.csv, CubesatPwrBoard.kicad_sch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]
2023-03-31 Added text file with list of changes to make to power board after having tested it
2023-05-03 Small changes to board before moving to previous-revision
    [Bat_Reg_1.kicad_sch, CubesatPwrBoard.kicad_sch]
2023-05-03 Major revision V5.0, will add to changelog later
    [Bat_Reg_1.kicad_sch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]
2023-05-03 Final V5 revision, should be ready for purchase
    [CubesatPwrBoard.kicad_pcb]
2023-05-03 rotated one designator
    [CubesatPwrBoard.kicad_pcb]
2023-05-03 Rotated one text symboland realigned mounting holes
    [CubesatPwrBoard.kicad_pcb]
2023-05-03 Adjusted some text
    [CubesatPwrBoard.kicad_pcb]
2023-05-03 Deleted some unecessary files
    [CubesatPwrBoard-B_Cu.gbl, CubesatPwrBoard-B_Mask.gbs, CubesatPwrBoard-B_Paste.gbp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]
2023-05-04 Added gerbers
    [CubesatPwrBoard-B_Cu.gbl, CubesatPwrBoard-B_Mask.gbs, CubesatPwrBoard-B_Paste.gbp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]
